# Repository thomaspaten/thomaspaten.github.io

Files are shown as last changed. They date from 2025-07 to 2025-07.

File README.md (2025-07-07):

# Arduino-Based Incubator Environmental Control System

## System Overview

This Arduino-based incubator environmental control system maintains precise temperature and humidity conditions across three distinct zones (TOP, BOT, and EXT) within a repurposed refrigerator housing, optimizing insulation and structural stability. Utilizing AHT20 sensors, PWM-controlled fans, dimmers and 100w incandescent lightbulbs. The system features advanced error handling, non-blocking operation, and biological process optimization.

### Wiring plan

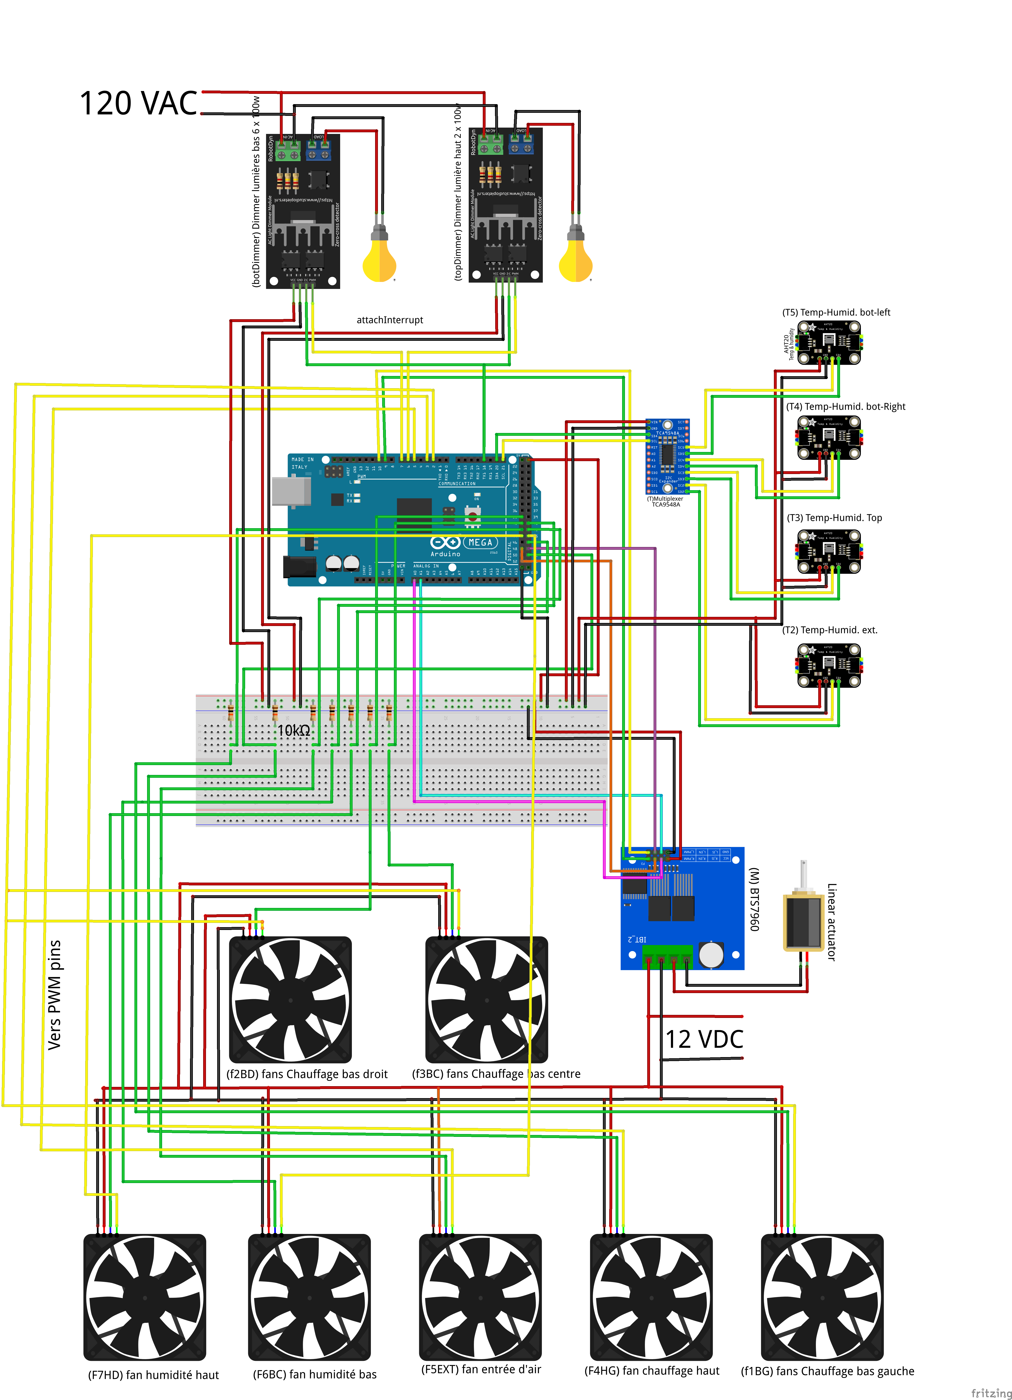
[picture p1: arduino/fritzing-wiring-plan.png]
Fritzing Wiring Plan


**Key Features:**

- Multi-zone climate control
- Redundant sensor systems
- Adaptive control algorithms
- Real-time monitoring
- Automatic failure recovery

---

# 1. System Architecture

## 1.1 Hardware Infrastructure

### 1.1.1 Microcontroller Configuration

The system is built on the **Arduino Mega 2560** platform, chosen for its extensive I/O capabilities and multiple hardware timers.

**Specifications:**

- **Processor**: ATmega2560 @ 16 MHz
- **Memory**: 256KB Flash, 8KB SRAM, 4KB EEPROM
- **Digital I/O**: 54 pins (15 PWM capable)
- **Analog Inputs**: 16 channels (10-bit resolution)
- **Hardware Timers**: 6 timers for precise PWM control

**Timer Allocation:**

```
Timer 0: Arduino millis() and delay() functions
Timer 1: Available for future expansion
Timer 2: Available for future expansion
Timer 3: PWM for pins 2, 3, 5 (fan control)
Timer 4: Available for future expansion
Timer 5: PWM for pins 44, 45 (fan control)
```

### 1.1.2 I2C Bus Architecture

The I2C communication backbone enables multiple identical sensors on a single bus through multiplexing.

**Physical Connection:**

```
Arduino Mega 2560
├── Pin 20 (SDA) ──┐
├── Pin 21 (SCL) ──┤
                   │
                   └─→ TCA9548A I2C Multiplexer (Address: 0x70)
                       ├── Channel 0: [Unused]
                       ├── Channel 1: [Unused]
                       ├── Channel 2: EXT Sensor (External/exterior)
                       ├── Channel 3: TOP Sensor (Upper Chamber)
                       ├── Channel 4: BOT_D Sensor (Bottom Door-side)
                       ├── Channel 5: BOT_G Sensor (Bottom Glass-side)
                       ├── Channel 6: [Reserved for expansion]
                       └── Channel 7: [Reserved for expansion]
```

**I2C Communication Parameters:**

- **Bus Speed**: 100 kHz (standard mode)
- **Pull-up Resistors**: 4.7kΩ on SDA and SCL
- **Multiplexer Control**: Single-byte channel selection
- **Error Detection**: ACK/NACK monitoring

### 1.1.3 Sensor Specifications (AHT20)

The AHT20 is a calibrated digital temperature and humidity sensor with I2C interface.

**Technical Specifications:**

| Parameter | Value |
| --- | --- |
| Temperature Range | -40°C to +85°C |
| Temperature Accuracy | ±0.3°C |
| Temperature Resolution | 0.01°C |
| Humidity Range | 0-100% RH |
| Humidity Accuracy | ±2% RH |
| Humidity Resolution | 0.024% RH |
| Response Time | 5-30 seconds |
| Supply Voltage | 2.0-5.5V |
| Supply Current | 23µA (typical) |
| Communication | I2C (max 400kHz) |

**Sensor Placement Rationale:**

- **EXT**: Monitors exterior conditions for compensation algorithms
- **TOP**: Upper chamber (hatcher), where warm air accumulates
- **BOT_D**: Bottom chamber (setter), where warm air accumulates on the right
- **BOT_G**: Bottom chamber (setter), where warm air accumulates on the left

## 1.2 Fan System Detailed Analysis

### 1.2.1 Fan Distribution and Purpose

The seven-fan system creates controlled airflow patterns for optimal environmental conditions.

**Fan Configuration Table:**

| Fan ID | Location | Pin | Function | Control Strategy |
| --- | --- | --- | --- | --- |
| F1BG | Bottom Chamber | 2 | Circulation | Temperature-based |
| F2BD | Bottom Chamber | 2 | Circulation | Temperature-based |
| F3BC | Bottom Chamber | 2 | Circulation | Temperature-based |
| F4HG | Top Chamber | 3 | Circulation | Temperature-based |
| F5EXT  | Exterior | 5 | Air exchange | Temp/Humidity hybrid |
| F6BC | Bottom Chamber | 45  | Humidity control | Humidity-based |
| F7HD | Top Chamber | 44  | Humidity control | Humidity-based |

**Shared PWM Design:** F1BG, F2BD, and F3BC share pin 2 to ensure synchronized operation

### 1.2.2 PWM Control Resolution

The system uses 8-bit PWM for fan speed control, providing 256 discrete speed levels.

**Speed Mapping:**

```cpp
// Percentage to PWM conversion
uint8_t percentageToPWM(uint8_t percentage) {
    return map(percentage, 0, 100, 0, 255);
}
```

**Predefined Speed Levels:**

| Level | Percentage | PWM Value | Use Case |
| --- | --- | --- | --- |
| OFF | 0% | 0 | No airflow needed |
| VERY_LOW | 25% | 64 | Minimal circulation |
| LOW | 50% | 128 | Gentle airflow |
| MEDIUM | 75% | 191 | Normal operation |
| HIGH | 100% | 255 | Maximum cooling/circulation |

**PWM Frequency:**

- Default: 490 Hz (Timer 3 and Timer 5)
- Audible noise: Minimal at this frequency

### 1.2.3 Tachometer Feedback System

Each fan provides RPM feedback through a tachometer output, enabling closed-loop monitoring.

**Tachometer Signal Characteristics:**

- **Type**: Open-collector output (requires pull-up resistor)
  - The pull-up resistor prevents a pin from being "floating," meaning it's neither high nor low, which can lead to unpredictable behavior.
- **Pulses per Revolution**: 2 (standard for 4-pole motors)
- **Signal Level**: 0-5V square wave

**Non-Blocking Pulse Measurement:**

```cpp
struct PulseData {
    unsigned long startTime = 0;  // Microsecond timestamp
    unsigned long duration = 0;   // Pulse width in microseconds
    bool pulseDetected = false;   // State tracking
};

// RPM Calculation
RPM = 60,000,000 / (pulse_duration × 4)
// Where: 60,000,000 = microseconds per minute
//        4 = 2 pulses/rev × 2 (for full period)
```

**Validation Ranges:**

- Minimum pulse: 1,000 µs (60,000 RPM - unrealistic, filtered)
- Maximum pulse: 1,000,000 µs (60 RPM - stall detection)

## 1.3 Heating System Architecture

### 1.3.1 Dimmer Control Implementation

The heating system uses AC phase control through TRIAC dimmers for precise temperature regulation.

**Hardware Components:**

- **Zero-Cross Detector**: Pin 18 (interrupt-capable)
- **TRIAC Driver (TOP)**: Pin 6
- **TRIAC Driver (BOT)**: Pin 7
- **Library**: `dimmable_light_linearized.h`

**Power Control Levels:**

| Setting | Power | Purpose |
| --- | ----- | --- |
| OFF | 0% | No heating required |
| LOW | 40% | Maintenance heating |
| MEDIUM  | 60% | [Unused in current config] |
| HIGH | 80% | Rapid temperature recovery |

**Safety Limitation:** Maximum 80% power prevents TRIAC overheating and extends the incandescent light bulb (100w) life.

### 1.3.2 AC Phase Control

The dimmer implements phase control for power regulation.

**Operating Principle:**

1. **Zero-Cross Detection**: Identifies AC waveform crossing zero volts
2. **Phase Delay**: Calculates delay based on desired power
3. **TRIAC Firing**: Triggers conduction at calculated point
4. **Power Delivery**: Earlier firing = more power

**Timing Calculations:**

```
AC Period = 16.67ms (60Hz) or 20ms (50Hz)
Half Period = 8.33ms (60Hz) or 10ms (50Hz)
Phase Angle = (1 - Power%) × Half Period
```

**Linear Compensation:** The library compensates for non-linear power delivery:

- Raw phase control: Power ∝ (Phase Angle)²
- Linearized output: Power ∝ Brightness setting

# 2. Environmental Control Algorithms

## 2.1 Temperature Control

### 2.1.1 TOP Chamber (Hatcher) Temperature Logic

The TOP chamber maintains optimal incubation temperature through coordinated heater and fan control.

**Temperature Zones and Responses:**

| Zone | Temperature Range | Heater Action | Fan F4HG Action | Rationale |
| --- | --- | --- | --- | --- |
| VERY_LOW | < 36.0°C | 80% Power | 100% Speed | Rapid warming with maximum circulation |
| LOW | 36.0-37.50°C | 40% Power | 75% Speed | Gentle warming approaching target |
| OPTIMAL  | 37.50-37.60°C | 0% Power | 50% Speed | Maintain with circulation only |
| HIGH | > 37.60°C | 0% Power | 100% Speed | Active cooling via air exchange with exterior |

**Control Logic Visualization:**

```
Temperature (°C)
    │
<36.0├─── VERY_LOW ─── Heater: 80%, Fan: 100%
    │
37.50├─── LOW ─────── Heater: 40%, Fan: 75%
    │
37.60├─── OPTIMAL ─── Heater: 0%, Fan: 50%
    │
  >  ├─── HIGH ────── Heater: 0%, Fan: 100%
    │
```

### 2.1.2 BOTTOM Chamber (Setter) Temperature Logic

The BOTTOM chamber uses averaged readings from two sensors to compensate for sensor inaccuracies.

**Dual Sensor Averaging:**

```cpp
float botTemperatureAvg = (botSensorData.temperatureD + botSensorData.temperatureG) / 2;
```

Averaging prevents control bias from single-point measurement

**Temperature Zones and Responses:**

| Zone | Temperature Range | Heater Action | Fans F1-F3 Action | Notes |
| --- | --- | --- | --- | --- |
| VERY_LOW | < 36.0°C | 80% Power | 100% Speed | Emergency heating |
| LOW | 36.0-37.54°C | 40% Power | 75% Speed | Normal warming |
| OPTIMAL  | 37.54-37.68°C | 0% Power | 50% Speed | Target achieved |
| HIGH | > 37.68°C | 0% Power | 100% Speed | Cooling required  |

### 2.1.3 External Temperature Compensation Algorithm

The system adapts to exterior conditions by modifying bottom chamber heater setpoints.

**Compensation Logic:**

```cpp
if (extTemperature < 18.0°C) {  // VERY_LOW_TEMP_EXT
    // Increase all bottom dimmer settings by 10%
    adjustedDimmerLow = DIMMER_LOW + 10;    // 40% → 50%
    adjustedDimmerHigh = DIMMER_HIGH + 10;  // 80% → 90%
} else if (extTemperature > 22.0°C) {  // LOW_TEMP_EXT
    // Decrease all bottom dimmer settings by 10%
    adjustedDimmerLow = max(0, DIMMER_LOW - 10);   // 40% → 30%
    adjustedDimmerHigh = max(0, DIMMER_HIGH - 10); // 80% → 70%
}
```

**Rationale:**

- **Cold exterior (<18°C)**: Increased heating to compensate for cool air coming from the exterior
- **Warm exterior (>22°C)**: Reduced heating to compensate for warm air coming from the exterior
- **Neutral Zone (18-22°C)**: Standard control parameters

## 2.2 Humidity Control

### 2.2.1 TOP Chamber Humidity Management

The TOP chamber requires higher humidity for hatching.

**Humidity Control Matrix:**

| State | RH Range | Fan F7HD | Strategy |
| --- | --- | --- | --- |
| VERY_LOW | < 55% | 100% | Maximum humidification |
| LOW | 55-62% | 100% | Active humidification |
| MEDIUM | 62-68% | 50% | Maintenance mode |
| HIGH | > 68% | 0% | Natural dehumidification |

**Humidity Source:**

- Water pan and fan
- Variations of fan speeds manage evaporation rate by blowing air on the water pan.

### 2.2.2 BOTTOM Chamber Humidity Management

The BOTTOM chamber maintains lower humidity for setting.

**Humidity Control Matrix:**

| State | RH Range | Fan F6BC | Purpose |
| --- | --- | --- | --- |
| VERY_LOW | < 40% | 100% | Prevent desiccation |
| LOW | 40-45% | 75% | Increase moisture |
| MEDIUM | 45-48% | 50% | Maintain balance |
| HIGH | > 52% | 0% | Allow natural reduction |

### 2.2.3 Humidity Override Mechanism

Critical humidity levels trigger emergency ventilation regardless of temperature.

**Override Implementation:**

```cpp
// In adjustFanAndDimmerForExt()
if (botHumidityAvg > 55.0%) {  // HIGH_HUMIDITY_BOT threshold
    analogWrite(PWM_F5EXT, percentageToPWM(FAN_HIGH));  // Force 100%
    // Message: "Fan F5EXT: High Speed (EXT_SENSOR override - Bot Humidity > 55.0%)"
}
```

**Override Cascade:**

1. Bottom humidity exceeds 55%
2. F5EXT forced to 100% (overrides temperature control)
3. Fresh, dry air exchanges with humid internal air
4. Continues until humidity drops below threshold

## 2.3 External Air Exchange Logic

### 2.3.1 Normal Operation

The external fan (F5EXT) operates on a hierarchical decision tree.

**Decision Priority (Highest to Lowest):**

```
1. IF (BOT_HUMIDITY > 55%):
      F5EXT = 100%  [Humidity Override]
      
2. ELSE IF (EXT_TEMP > 36.8°C):
      F5EXT = 100%  [Active Cooling]
      
3. ELSE:
      F5EXT = 25%   [Baseline Ventilation]
```

**Operational Modes:**

| Mode | Condition | Fan Speed | Purpose |
| --- | --- | --- | --- |
| Emergency Dehumidification | Bot RH > 55% | 100% | Moisture removal |
| Active Cooling | Ext Temp > 36.8°C | 100% | Cooling of electronic enclosure |
| Baseline Ventilation | All other conditions | 25% | Gas exchange |

### 2.3.2 Air Quality Management

Continuous baseline ventilation ensures biological viability.

**Gas Exchange Requirements:**

- **O₂ Supply**: Embryonic respiration consumes oxygen
- **CO₂ Removal**: Metabolic waste product must be expelled
- **VOC Dilution**: Volatile organic compounds from biological processes

# 3. Sensor Reading and Data Processing

## 3.1 Timing Architecture

### 3.1.1 Reading Cycle Timeline

The sensor reading process follows a deterministic schedule to ensure predictable system behavior.

**Complete Cycle Breakdown:**

```
Time (ms)    Event                           Duration    Cumulative
─────────────────────────────────────────────────────────────────
0            Cycle Start                     -           0ms
0-500        Read EXT sensor (Channel 2)     500ms       500ms
500-1000     Read TOP sensor (Channel 3)     500ms       1000ms
1000-1500    Read BOT_D sensor (Channel 4)   500ms       1500ms
1500-2000    Read BOT_G sensor (Channel 5)   500ms       2000ms
2000-2100    Calculate averages              100ms       2100ms
2100-2200    Adjust controls                 100ms       2200ms
2200-2300    Update displays                 100ms       2300ms
2300-3000    Idle time                       700ms       3000ms
3000         Next cycle begins               -           -
```

**Timing Guarantees:**

- Maximum sensor read time: 500ms (includes retries)
- Control update latency: <100ms after sensor read
- Worst-case cycle time: 3000ms
- Watchdog margin: 5000ms (8000ms timeout - 3000ms cycle)

### 3.1.2 Non-Blocking Implementation

The system uses state machines to prevent blocking operations.

**Main Loop State Machine:**

```cpp
// Sensor reading states
static bool readingInProgress = false;
static int sensorIndex = 0;

// Cycle trigger
if (currentMillis - previousSensorMillis >= readInterval && !readingInProgress) {
    previousSensorMillis = currentMillis;
    sensorIndex = 0;
    readingInProgress = true;
}

// Sensor reading progression
if (readingInProgress && currentMillis - sensorDelayMillis >= sensorDelayInterval) {
    // Read current sensor
    // Increment sensorIndex
    // Set readingInProgress = false when complete
}
```

**Benefits:**

- No delay() calls that would block execution
- Continuous fan RPM monitoring
- Responsive to emergency conditions
- Prevents watchdog timeouts

## 3.2 Data Validation and Filtering

### 3.2.1 Validation Criteria

All sensor readings undergo validation before use.

**Validation Function:**

```cpp
bool isValidReading(float value, float minVal, float maxVal) {
    return !isnan(value) && value >= minVal && value <= maxVal;
}
```

**Range Limits:**

| Parameter | Minimum | Maximum | Action if Invalid  |
| --- | --- | --- | --- |
| Temperature | -40.0°C | +85.0°C | Use fallback value |
| Humidity | 0.0% | 100.0%  | Use fallback value |

**NaN Detection:**

- Caused by: Communication errors, sensor failure
- Response: Immediate fallback to calculated estimate

### 3.2.2 Moving Average Implementation

The system maintains 100-sample circular buffers to get an average of the last 100 sensors readings.

**Buffer Structure:**

```cpp
// Temperature arrays
float topTemperatures[100];
float botDTemperatures[100];
float botGTemperatures[100];

// Humidity arrays
float topHumidities[100];
float botDHumidities[100];
float botGHumidities[100];

// Circular index
int readingIndex = 0;
```

**Average Calculation:**

```cpp
float calculateAverage(float readings[], int n) {
    float sum = 0;
    for (int i = 0; i < n; i++) {
        sum += readings[i];
    }
    return sum / n;
}
```

**Filtering Performance:**

- **Sample Window**: 300 seconds (100 samples × 3 seconds)
- **Effective Resolution**: 0.03°C (from 0.3°C sensor accuracy)

## 3.3 Failure Management

### 3.3.1 Sensor Health Tracking

Each sensor maintains health statistics for reliability monitoring.

**Health Metrics:**

```cpp
struct SensorHealth {
    int successfulReads = 0;  // Cumulative success count
    int failedReads = 0;      // Cumulative failure count
};
```

**Failure Escalation:**

1. **Single Failure**: Retry up to 3 times
2. **Persistent Failure**: Increment failure counter
3. **Chronic Failure**: After 10 failures, disable sensor
4. **Recovery Check**: Every 60 seconds, attempt re-enable

**Health Status Display every 300 seconds (Serial Monitor):**

```
Sensor Health Status:
EXT - Successful Reads: 1200, Failed Reads: 2
TOP - Successful Reads: 1198, Failed Reads: 4
BOT_D - Successful Reads: 1201, Failed Reads: 1
BOT_G - Successful Reads: 1202, Failed Reads: 0
```

### 3.3.2 Fallback Strategy

Intelligent fallback values maintain system operation during sensor failures.

**Temperature Fallback Logic:**

```cpp
float getFallbackTemperature(int sensorIndex) {
    switch (sensorIndex) {
        case EXT:   return 25.0;  // Assume room temperature
        case TOP:   return botSensorData.temperatureD - 0.3;  // Thermal model
        case BOT_D: return botSensorData.temperatureG;  // Adjacent sensor
        case BOT_G: return botSensorData.temperatureD;  // Adjacent sensor
    }
}
```

**Humidity Fallback Logic:**

```cpp
float getFallbackHumidity(int sensorIndex) {
    switch (sensorIndex) {
        case EXT:   return 50.0;  // Assume moderate humidity
        case TOP:   return botSensorData.humidityD + 15.0;  // Evaporation model
        case BOT_D: return botSensorData.humidityG;  // Adjacent sensor
        case BOT_G: return botSensorData.humidityD;  // Adjacent sensor
    }
}
```

**Fallback Rationale:**

- **Thermal Stratification**: TOP is typically 0.3°C cooler than BOT
- **Humidity Gradient**: TOP is ~15% more humid due to hatching requirements
- **Adjacent Correlation**: BOT sensors typically within 0.1°C of each other

## 3.4 I2C Communication Robustness

### 3.4.1 Channel Selection State Machine

Multi-stage error handling ensures reliable multiplexer control.

**State Definitions:**

```
State 0: Idle - Ready to start new transmission
State 2: Retry - Previous attempt failed, waiting to retry
State 3: Bus Reset - Multiple failures, attempting recovery
```

**State Transitions:**

```
    ┌─────┐ Success  ┌─────┐
    │  0  ├─────────→│Done │
    │Idle │          └─────┘
    └──┬──┘
       │ Failure
       ▼
    ┌─────┐ Retry<3   ┌─────┐
    │  2  ├──────────→│ 0   │
    │Retry│           │Idle │
    └──┬──┘           └─────┘
       │ Retry≥3
       ▼
    ┌─────┐ Reset OK  ┌─────┐
    │  3  ├──────────→│ 0   │
    │Reset│           │Idle │
    └─────┘           └─────┘
```

**Timing Parameters:**

- Retry delay: 50ms
- Maximum retries: 3
- Bus reset duration: 100ms
- Total timeout: 250ms

### 3.4.2 Bus Recovery Mechanism

Hardware-level recovery clears stuck I2C devices.

**Recovery Sequence:**

```cpp
void resetI2CBus() {
    // 1. Take control of I2C pins
    pinMode(SDA_PIN, OUTPUT);
    pinMode(SCL_PIN, OUTPUT);
    
    // 2. Clock out stuck devices (9 pulses)
    for (int i = 0; i < 9; i++) {
        digitalWrite(SCL_PIN, HIGH);
        delayMicroseconds(5);
        digitalWrite(SCL_PIN, LOW);
        delayMicroseconds(5);
    }
    
    // 3. Generate STOP condition
    digitalWrite(SDA_PIN, LOW);   // SDA low
    delayMicroseconds(5);
    digitalWrite(SCL_PIN, HIGH);  // SCL high
    delayMicroseconds(5);
    digitalWrite(SDA_PIN, HIGH);  // SDA high (STOP)
    
    // 4. Return control to I2C hardware
    pinMode(SDA_PIN, INPUT);
    pinMode(SCL_PIN, INPUT);
    Wire.begin();
}
```

**Recovery Triggers:**

- 3 consecutive NAKs from multiplexer
- Wire.endTransmission() returns error
- Sensor initialization timeout

# 4. Control System Dynamics

Different subsystems operate at optimized update rates.

**Update Frequency Table:**

| Subsystem | Frequency  | Period | Priority |
| --- | --- | --- | --- |
| Sensor Reading | 0.33 Hz | 3 seconds  | High |
| Control Output | 0.33 Hz | 3 seconds  | High |
| Fan RPM | Continuous | ~1ms | Low |
| Actuator State | Continuous | <1ms | Medium |
| Health Check | 0.017 Hz | 60 seconds | Low |
| Debug Print | 0.011 Hz | 90 seconds | Lowest |

**Timing Hierarchy:**

1. **Critical Path**: Sensor → Control → Output (3.2 seconds)
2. **Background Tasks**: RPM monitoring (continuous)
3. **Maintenance**: Health checks (60 seconds)
4. **Diagnostics**: Debug output (90 seconds)

# 5. Advanced Features

## 5.1 Linear Actuator System

### 5.1.1 Movement Sequence

The actuator system provides programmable eggs rotation.

**Complete Sequence Timeline:**

| Phase | Duration | Action | Purpose |
| --- | --- | --- | --- |
| Initial Retract | 60 seconds | Full retraction | Return to home position |
| Initial Stop | 10 seconds | Hold position | Stabilization |
| Extension Cycle (×11)  | | | |
| - Extend | 3 seconds  | Forward movement  | Agitation |
| - Stop | 13 minutes | Hold position | Settling time |
| Retraction Cycle (×11) | | | |
| - Retract | 3 seconds  | Backward movement | Return stroke |
| - Stop | 13 minutes | Hold position | Settling time |
| System Reset | Immediate  | Watchdog timeout  | Clean restart |

**Total Cycle Duration:**

```
Initial: 60 + 10 = 70 seconds
Extensions: 11 × (3 + 780) = 8,613 seconds
Retractions: 11 × (3 + 780) = 8,613 seconds
Total: 17,296 seconds ≈ 4.8 hours
```

**Motor Control Logic:**

```cpp
void controlMotor(bool enable, int dir) {
    if (enable) {
        digitalWrite(R_PWM, dir == 1 ? HIGH : LOW);   // Forward
        digitalWrite(L_PWM, dir == -1 ? HIGH : LOW);  // Reverse
        digitalWrite(R_EN, HIGH);  // Enable right
        digitalWrite(L_EN, HIGH);  // Enable left
    } else {
        digitalWrite(R_EN, LOW);   // Disable all
        digitalWrite(L_EN, LOW);
        digitalWrite(R_PWM, LOW);
        digitalWrite(L_PWM, LOW);
    }
}
```

### 5.1.2 Purpose Analysis

The actuator system simulates natural incubation movements.

**Biological Rationale:**

1. **Prevents Adhesion**
    - Embryo can stick to membrane
    - Periodic movement prevents attachment
    - Critical during days 3-18 of incubation
    
2. **Uniform Development**
    - Redistributes nutrients in albumen
    - Prevents yolk stratification
    - Ensures even temperature distribution
    
3. **Gas Exchange**
    - Movement enhances air cell formation
    - Facilitates CO₂ removal from egg
    - Improves O₂ penetration
    
4. **Natural Simulation**
    - Mimics parent bird movements
    - 3-second duration = gentle repositioning

**Movement Profile:**

```
Position
    │     ┌─3s─┐     ┌─3s─┐
MAX ├─────┘    └──-──┘    └────-                              
    │ 13min     13min      13min
```

## 5.2 Watchdog Timer Implementation

### 5.2.1 Normal Operation

The watchdog prevents system lockup through automatic reset.

**Configuration:**

```cpp
// In setup()
wdt_enable(WDTO_8S);  // 8-second timeout

// Throughout loop()
wdt_reset();  // Called multiple times per cycle
```

**Reset Prevention Points:**

1. Start of main loop
2. After sensor reading
3. During long operations

**Timeout Scenarios:**

- I2C bus permanently locked
- Infinite loop in user code
- Hardware malfunction
- Stack overflow

### 5.2.2 Intentional Reset

The system uses watchdog for controlled restart after actuator sequence.

**Reset Implementation:**

```cpp
if (sequenceCount >= REPETITIONS) {
    // After last retraction
    wdt_enable(WDTO_15MS);  // 15ms timeout
    while (true) {
        // Intentional infinite loop
        // Watchdog will reset in 15ms
    }
}
```

**Reset Benefits:**

- Clears accumulated errors
- Resets memory allocation
- Re-initializes all peripherals
- Returns actuator to home
- Provides known starting state

**Reset Sequence:**

1. Watchdog expires (15ms)
2. Processor resets
3. Bootloader runs (2 seconds)
4. Setup() executes
5. Normal operation resumes

## 5.3 Debug and Monitoring

### 5.3.1 Cyclic Reporting

Debug output occurs every 30 sensor cycles (90 seconds).

**Serial Monitor Contents:**

```
=========================================
EXT - Temperature: 22.3 °C, Humidity: 45.2 %
TOP - Temperature: 37.52 °C, Humidity: 66.8 %
BOT-Av - Temperature: 37.58 °C, Humidity: 47.3 %

EXT: F5EXT: 1250 RPM
TOP: F4HG: 2100 RPM, F7HD: 0 RPM
BOT: F1BG: 1800 RPM, F2BD: 1850 RPM, F3BC: 1820 RPM, F6BC: 950 RPM

TOP Average 100 Temperature:   37.51 °C
BOT_D Average 100 Temperature: 37.56 °C
BOT_G Average 100 Temperature: 37.59 °C

TOP Average 100 Humidity:   66.5 %
BOT_D Average 100 Humidity: 46.8 %
BOT_G Average 100 Humidity: 47.8 %

Next Linear actuator sequence: 5 of 11 EXTENDING_SEQUENCE
=========================================

Sensor Health Status:
EXT - Successful Reads: 1200, Failed Reads: 2
TOP - Successful Reads: 1198, Failed Reads: 4
BOT_D - Successful Reads: 1201, Failed Reads: 1
BOT_G - Successful Reads: 1202, Failed Reads: 0
=========================================
```

### 5.3.2 Conditional Logging

Intelligent logging reduces serial bandwidth usage.

**shouldPrint() Logic:**

```cpp
bool shouldPrint() {
    return cycleCounter % PRINT_CYCLE_INTERVAL == 0;
}
// PRINT_CYCLE_INTERVAL = 30 cycles = 90 seconds
```

**Benefits:**

- Reduces processing overhead
- Prevents serial buffer overflow
- Maintains 115200 baud efficiency
- Allows real-time monitoring without flooding

# 6. System Integration and Real-World Behavior

## 6.1 Startup Sequence

The system follows a deterministic initialization sequence.

**Startup Timeline:**

| Time | Phase | Actions | Duration |
| --- | --- | --- | --- |
| 0ms | Power On | Bootloader execution | 2000ms |
| 2000ms  | Setup Start | Serial initialization | 10ms |
| 2010ms  | GPIO Config | Pin modes, initial states | 50ms |
| 2060ms  | Peripheral Init  | Dimmers, I2C, Watchdog | 100ms |
| 2160ms  | Sensor Discovery | Channel scan, AHT20 init  | 5000ms max |
| 7160ms  | Control Start | First sensor read | 3000ms |
| 10160ms | Steady State | Normal operation | Continuous |

**Initialization Details:**

1. **GPIO Configuration**
    
    ```cpp
    // Outputs set to safe states
    All PWM pins → 0 (fans off)
    Heater pins → 0 (heaters off)
    Motor pins → 0 (actuator stopped)
    ```
    
2. **Sensor Discovery Process**
    
    ```cpp
    For each channel (2-5):
      - Select multiplexer channel
      - Attempt AHT20.begin()
      - 5-second timeout per sensor
      - Continue with available sensors
    ```
    
3. **Initial Control State**
    
    - All fans: 0% (will ramp up based on readings)
    - All heaters: 0% (safety first)
    - Actuator: Begin 60-second retraction to ensure actuator is completely retracted before starting sequence.

## 6.2 Steady-State Operation

### 6.2.1 24-Hour Profile Example

The system adapts to environmental changes.

| Time Period | External Conditions | System Response |
| --- | --- | --- |
| 00:00-06:00 | Cool (15-18°C), Stable | Increased heating, minimal ventilation |
| 06:00-09:00 | Warming (18-22°C) | Reduced heating, baseline ventilation  |
| 09:00-15:00 | Warm (22-30°C) | Minimal heating, increased ventilation |
| 15:00-18:00 | Peak (28-35°C) | No heating, maximum cooling efforts |
| 18:00-21:00 | Cooling (25-20°C) | Gradual heating increase |
| 21:00-00:00 | Cool (20-15°C) | Return to night settings |

## 6.3 Failure Scenarios and Recovery

### 6.3.1 Sensor Failure Cascade

**Failure Progression:**

```
1. Single Sensor Failure
   ├── Use fallback value
   ├── Continue normal operation
   └── Log failure for diagnostics

2. Paired Sensor Failure (BOT_D + BOT_G)
   ├── Use TOP - 0.3°C for temperature
   ├── Use TOP - 15% for humidity
   └── Increase safety margins

3. Zone Failure (All BOT or TOP)
   ├── Use remaining zone data
   ├── Apply conservative estimates
   └── Alert via serial output

4. Total Sensor Failure
   ├── Use default values (25°C, 50% RH)
   ├── Run fans at 50%
   ├── Run heaters at 20%
   └── Safe mode operation
```

**Recovery Mechanisms:**

- Automatic retry every 60 seconds
- I2C bus reset on communication failure
- Sensor re-initialization attempts
- Gradual trust rebuilding after recovery

# 7. Biological Considerations

## 7.1 Incubation Requirements

### 7.1.1 Temperature Precision

Critical temperature ranges for successful incubation.

**Species-Specific Requirements:**

| Species | Optimal Range | Critical Limits | Duration |
| --- | --- | --- | --- |
| Chicken | 37.5-37.8°C | 36.1-39.4°C | 21 days  |
| Duck | 37.5°C | 36.0-39.0°C | 28 days  |
| Quail | 37.6-37.8°C | 36.5-39.0°C | 17 days  |
| Turkey  | 37.5-37.6°C | 36.0-39.0°C | 28 days  |

**Temperature Impact on Development:**

- **Too Low (<36°C)**: Delayed development, weakness
- **Optimal (37.5°C)**: Normal development rate
- **Too High (>39°C)**: Accelerated but abnormal development
- **Lethal (>40°C)**: Protein denaturation, death

### 7.1.2 Humidity Management

Moisture control for proper development.

**Humidity Requirements by Stage:**

| Incubation Stage | Days  | Target RH | Purpose |
| --- | ----- | --- | --- |
| Early | 1-7 | 50-60% | Prevent excess water loss |
| Middle | 8-18  | 45-55% | Controlled dehydration |
| Late | 19-21 | 65-75% | Facilitate hatching |

**Humidity Effects:**

- **Too Low (<40%)**: Excessive water loss, stuck chicks
- **Optimal (50-55%)**: Proper air cell development
- **Too High (>75%)**: Insufficient water loss, drowning

**Water Loss Targets:**

- Total loss: 12-15% of initial egg weight
- Daily rate: 0.5-0.7% of egg weight
- Monitored by candling

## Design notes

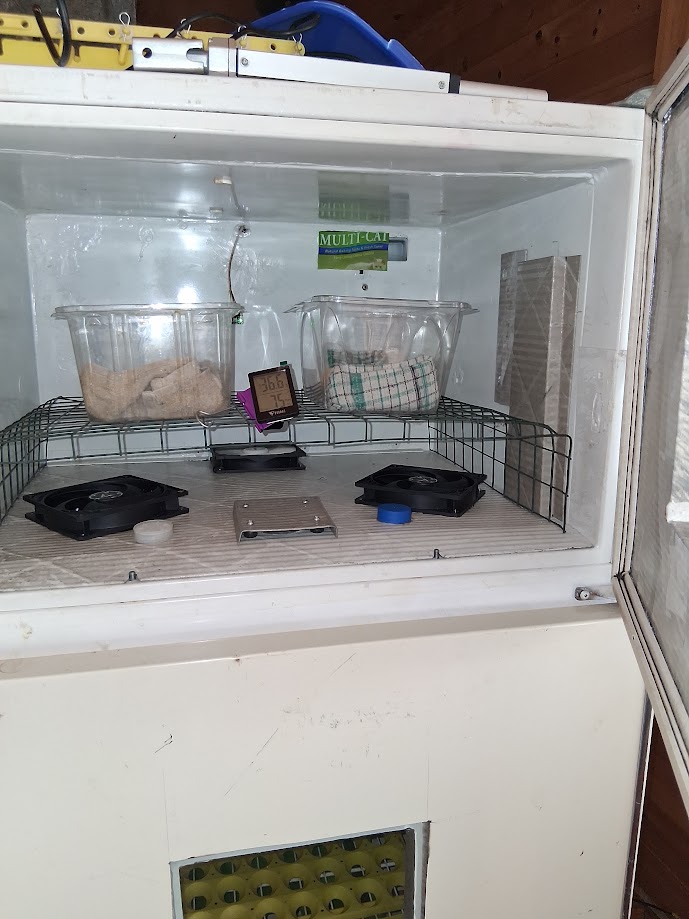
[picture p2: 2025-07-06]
dist/assets/top-section-D4AaJDt0.jpg

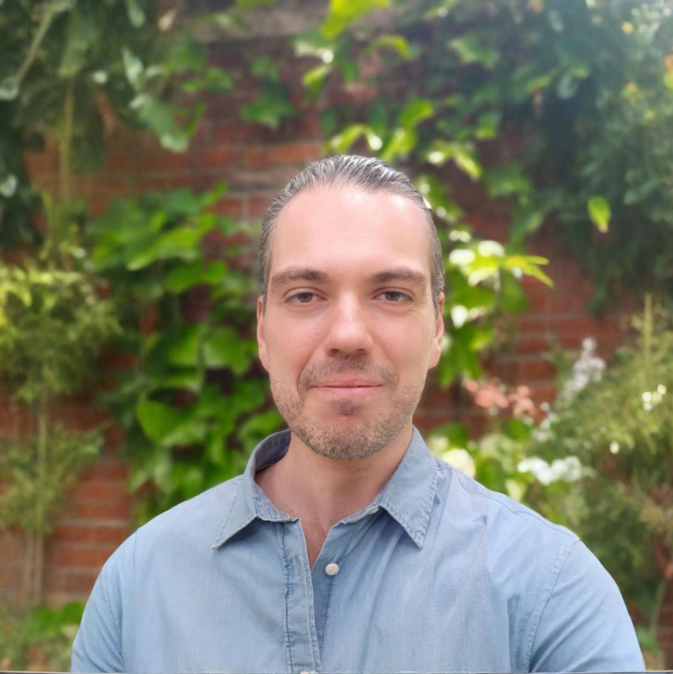
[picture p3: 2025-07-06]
dist/assets/linkedin-profile-MUepS1IG.png

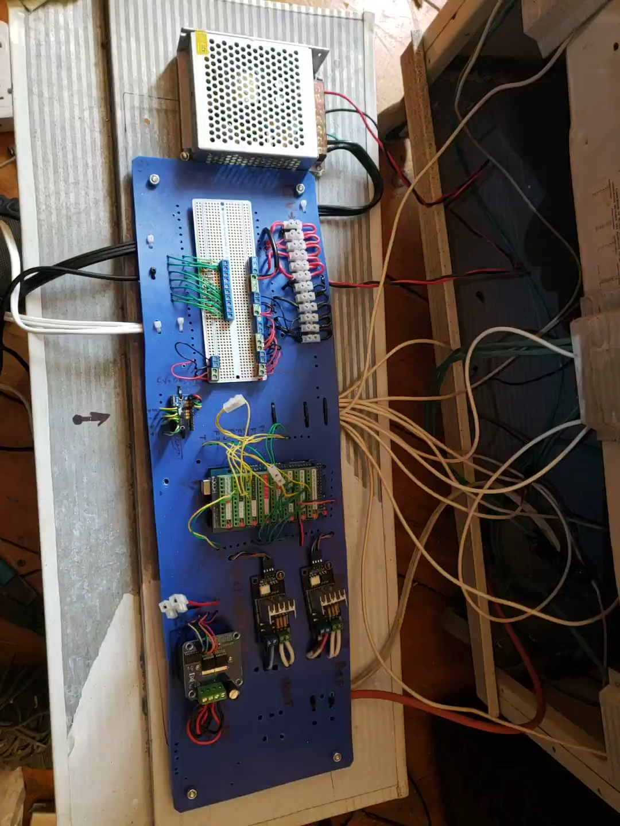
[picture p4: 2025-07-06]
dist/assets/arduino-circuit-CAp-xd5A.png

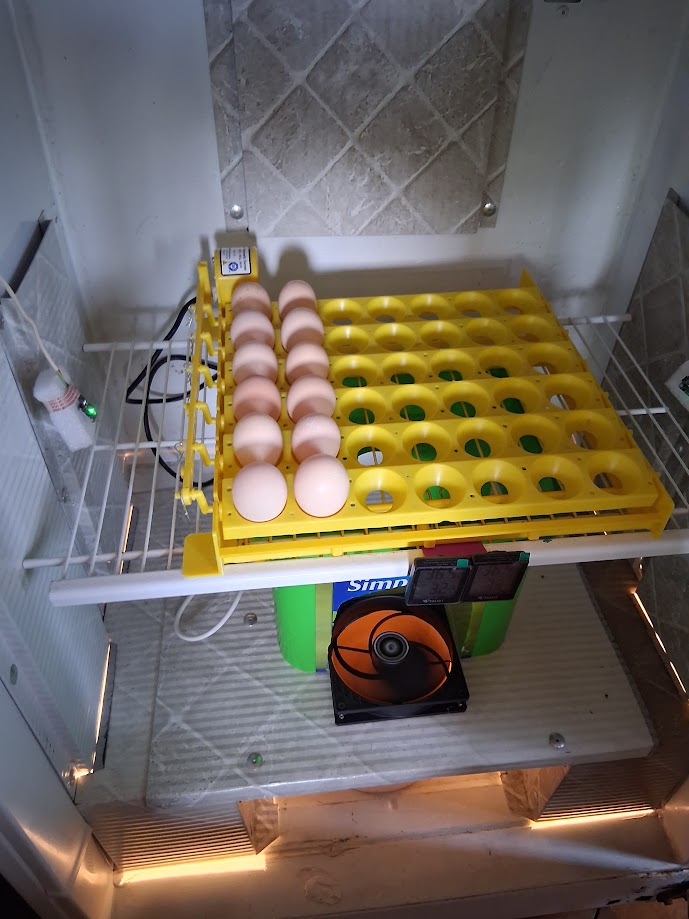
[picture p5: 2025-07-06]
dist/img/bottom-section.jpg

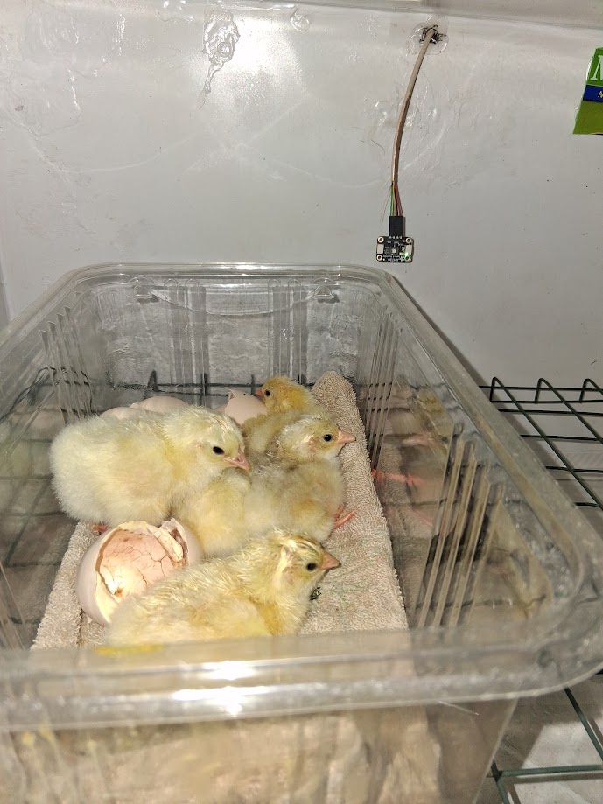
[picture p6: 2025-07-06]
dist/assets/hatched-chick-DnAsckwr.jpg

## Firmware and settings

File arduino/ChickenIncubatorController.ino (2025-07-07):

/*
VERY IMPORTANT
For <dimmable_light_linearized.h> to work, Arduino AVR board must be version 1.8.2 or lower 
(Menu - Tool - Board - Boards manager)
*/

/*
Summary of Conditions for Dimmers and Fans Adjustments

                  TEMPERATURE         DIMMER        FANS                          TARGET
Top
Very Low Temp     (< 36.0°C)	        High (80%)	  F4HG: High (100%)             -
Low Temp          (36.0°C - 37.35°C)	Low (40%)	    F4HG: Medium (75%)            -
Medium Temp       (37.35°C - 37.45°C)	Off (0%)	    F4HG: Low (50%)               37.2–37.5°C
High Temp         (> 37.45°C)	        Off (0%)	    F4HG: High (100%)             -

Very Low Humidity (< 55.0%)	          -	            F7HD: High (100%)             - 
Low Humidity      (55.0% - 65.0%)	    -	            F7HD: Medium (75%)            -
Medium Humidity   (65.0% - 74.0%)	    -	            F7HD: Very Low (25%)          65–75%
High Humidity     (> 74.0%)	          -	            F7HD: Off (0%)

Bot
Very Low Temp     (< 36.0°C)	        High (80%)	  F1BG_F2BD_F3BC: High (100%)   -
Low Temp          (36.0°C - 37.45°C)	Low (40%)	F1BG_F2BD_F3BC: Medium (75%)  -
Medium Temp       (37.45°C - 37.55°C)	Off (0%)	    F1BG_F2BD_F3BC: Low (50%)     37.5°C
High Temp         (> 37.55°C)	        Off (0%)	    F1BG_F2BD_F3BC: High (100%)   -

Very Low Humidity (< 40.0%)	          -	            F6BC: High (100%)             -
Low Humidity      (40.0% - 50.0%)	    -	            F6BC: Medium (75%)            -
Medium Humidity   (50.0% - 55.0%)	    -	            F6BC: Very Low (25%)          50–55%
High Humidity     (> 55.0%)	          -	            F6BC: Off (0%)                -

Ext
High Temp         (> 36.8°C)	        -	            F5EXT: High (100%)            -
Otherwise	                            -	            F5EXT: Very Low (25%)         -
*/

#include <Wire.h>                       // Library for I2C communication (sensors and multiplexer)
#include <Adafruit_AHTX0.h>             // Library for AHT20 temperature/humidity sensor
#include <dimmable_light_linearized.h>  // Library for controlling dimmable lights
#include <avr/wdt.h>                    // Library for watchdog timer (system reset on failure)

// ====================
// Constants
// ====================

// Printing cycles
constexpr int PRINT_CYCLE_INTERVAL = 30;  // Interval (in cycles) for printing debug info
constexpr int N_READINGS = 100;            // Number of readings for sensor temperature averaging

// ====================
// Pin Definitions
// ====================

// PWM Fan Pins (Default Arduino Mega frequency)
constexpr int PWM_F1BG_F2BD_F3BC = 2;  // Shared PWM pin for fans F1BG, F2BD, F3BC (Timer 3)
constexpr int PWM_F4HG = 3;            // PWM pin for fan F4HG (Timer 3)
constexpr int PWM_F5EXT = 5;           // PWM pin for fan F5EXT (Timer 3)
constexpr int PWM_F6BC = 45;           // PWM pin for fan F6BC (Timer 5)
constexpr int PWM_F7HD = 44;           // PWM pin for fan F7HD (Timer 5)

// TACH Fan Pins (for reading fan speed)
constexpr int TACH_F1BG = 42;   // TACH pin for fan F1BG (reads RPM)
constexpr int TACH_F2BD = 38;   // TACH pin for fan F2BD (reads RPM)
constexpr int TACH_F3BC = 40;   // TACH pin for fan F3BC (reads RPM)
constexpr int TACH_F4HG = 51;   // TACH pin for fan F4HG (reads RPM)
constexpr int TACH_F5EXT = 43;  // TACH pin for fan F5EXT (reads RPM)
constexpr int TACH_F6BC = 41;   // TACH pin for fan F6BC (reads RPM)
constexpr int TACH_F7HD = 47;   // TACH pin for fan F7HD (reads RPM)

// I2C Multiplexer Address
constexpr int TCA9548A_ADDRESS = 0x70;  // Address of TCA9548A I2C multiplexer

// Dimmable Light Pins
constexpr int dimmerZeroCrossPin = 18;  // Pin for zero-crossing detection (dimmer control)
constexpr int topDimmerOutputPin = 6;   // Pin for top dimmer output (brightness control)
constexpr int botDimmerOutputPin = 7;   // Pin for bottom dimmer output (brightness control)

// Motor driver pins (Linear Actuator)
constexpr int R_EN = 48;   // Right enable pin for motor driver
constexpr int L_EN = 49;   // Left enable pin for motor driver
constexpr int R_PWM = 10;  // Right PWM pin for motor driver
constexpr int L_PWM = 9;   // Left PWM pin for motor driver

// I2C Bus Reset Pins (assuming SDA = 20, SCL = 21 on Arduino Mega)
constexpr int SDA_PIN = 20;  // I2C SDA pin
constexpr int SCL_PIN = 21;  // I2C SCL pin

// ====================
// Constants
// ====================

// Number of Sensors
constexpr int NUM_SENSORS = 4;  // Total number of temp/humidity sensors

// Sensor Names (used to identify sensors in code and output)
enum SensorName { EXT, TOP, BOT_D, BOT_G };  // Enum for sensor naming

// Convert SensorName enum to readable string
const char* getSensorName(SensorName sensor) {
  switch (sensor) {
    case EXT: return "EXT";
    case TOP: return "TOP";
    case BOT_D: return "BOT_D";
    case BOT_G: return "BOT_G";
    default: return "UNKNOWN";
  }
}

// Temperature Thresholds
constexpr float VERY_LOW_TEMP_TOP = 36;    // Very low temp threshold for TOP sensor (°C)
constexpr float LOW_TEMP_TOP = 37.50;      // Low temp threshold for TOP sensor (°C) was 37.38
constexpr float HIGH_TEMP_TOP = 37.60;     // High temp threshold for TOP sensor (°C) was 37.48

constexpr float VERY_LOW_TEMP_BOT = 36;    // Very low temp threshold for BOT sensors (°C)
constexpr float LOW_TEMP_BOT = 37.54;      // Low temp threshold for BOT sensors (°C)
constexpr float HIGH_TEMP_BOT = 37.68;     // High temp threshold for BOT sensors (°C)

constexpr float VERY_LOW_TEMP_EXT = 18.0;  // Very low temp threshold for EXT sensor (°C)
constexpr float LOW_TEMP_EXT = 22.0;       // Low temp threshold for EXT sensor (°C)
constexpr float HIGH_TEMP_EXT = 36.8;      // High temp threshold for EXT sensor (°C)

// Humidity Thresholds
constexpr float VERY_LOW_HUMIDITY_TOP = 55.0;  // Very low humidity threshold for TOP (%)
constexpr float LOW_HUMIDITY_TOP = 62.0;       // Low humidity threshold for TOP (%) was 65
constexpr float MEDIUM_HUMIDITY_TOP = 68.0;    // Medium humidity threshold for TOP (%) was 74
constexpr float HIGH_HUMIDITY_TOP = 68.0;      // High humidity threshold for TOP (%) was 74

constexpr float VERY_LOW_HUMIDITY_BOT = 40.0;  // Very low humidity threshold for BOT (%)
constexpr float LOW_HUMIDITY_BOT = 45.0;       // Low humidity threshold for BOT (%) était 50
constexpr float MEDIUM_HUMIDITY_BOT = 48.0;    // Medium humidity threshold for BOT (%) était 55
constexpr float HIGH_HUMIDITY_BOT = 52.0;      // High humidity threshold for BOT (%) était 55

// Fan Speed Thresholds (in percentage)
constexpr int FAN_OFF = 0;        // Fan off (0% speed)
constexpr int FAN_VERY_LOW = 25;  // Fan speed at 25%
constexpr int FAN_LOW = 50;       // Fan speed at 50%
constexpr int FAN_MEDIUM = 75;    // Fan speed at 75%
constexpr int FAN_HIGH = 100;     // Fan speed at 100%

// Dimmer Brightness Thresholds (in percentage)
constexpr int DIMMER_OFF = 0;      // Dimmer off (0% brightness)
constexpr int DIMMER_LOW = 40;     // Dimmer brightness at 40%
constexpr int DIMMER_MEDIUM = 60;  // Dimmer brightness at 60%
constexpr int DIMMER_HIGH = 80;    // Dimmer brightness at 80%

// PWM and Timing Constants
constexpr int PWM_MAX_VALUE = 255;  // Max value for 8-bit PWM (100%)

// Sensor Timing
constexpr long readInterval = 3000;        // Interval for reading all sensors (ms)
constexpr long sensorDelayInterval = 500;  // Delay between individual sensor reads (ms)

// Error Handling Constants
constexpr int MAX_READ_ATTEMPTS = 3;    // Max attempts to read a sensor
constexpr int DEFAULT_TEMP = 25.0;      // Default temp if EXT sensor fails (°C)
constexpr int DEFAULT_HUMIDITY = 50.0;  // Default humidity if sensor fails (%)
constexpr int MAX_FAILURES_BEFORE_DISABLE = 10;  // Failures before disabling sensor

// Watchdog Timer Timeout
constexpr int WATCHDOG_TIMEOUT = 8000;  // 8s watchdog timeout (ms)

// Actuator Timing Constants
constexpr unsigned long RETRACT_DURATION = 60000;       // 60s initial retraction (ms)
constexpr unsigned long INITIAL_STOP_DURATION = 10000;  // 10s initial stop (ms)
constexpr unsigned long EXTEND_TIME = 3000;             // 3s extend time (ms)
constexpr unsigned long RETRACT_TIME = 3000;            // 3s retract time (ms)
constexpr unsigned long STOP_TIME = 780000;             // 13 min stop time (ms)
constexpr int REPETITIONS = 11;                         // Number of actuator cycles

// Actuator State Machine
enum State {
  RETRACTING_INITIAL,   // Initial retraction phase
  STOPPING_INITIAL,     // Initial stop phase
  EXTENDING_SEQUENCE,   // Extending sequence phase
  RETRACTING_SEQUENCE,  // Retracting sequence phase
  STOPPING              // Stop phase
};

// Pulse Measurement Constants
constexpr unsigned long MIN_PULSE_DURATION = 1000;    // Min valid pulse duration (µs)
constexpr unsigned long MAX_PULSE_DURATION = 1000000; // Max valid pulse duration (µs)

// Valid Range for Temperature and Humidity
constexpr float MIN_VALID_TEMP = -40.0;    // Min valid temperature (°C)
constexpr float MAX_VALID_TEMP = 85.0;     // Max valid temperature (°C)
constexpr float MIN_VALID_HUMIDITY = 0.0;  // Min valid humidity (%)
constexpr float MAX_VALID_HUMIDITY = 100.0;// Max valid humidity (%)

// I2C Retry Constants
constexpr int MAX_I2C_RETRIES = 3;      // Max retries for I2C communication
constexpr int RETRY_DELAY = 50;         // Delay between I2C retries (ms)
constexpr int BUS_RESET_DELAY = 100;    // Delay after bus reset (ms)
constexpr int BUS_RECOVERY_INTERVAL = 60000;  // Interval to reattempt recovery (ms)

// Sensor Initialization Timeout Constants
constexpr unsigned long SENSOR_INIT_TIMEOUT = 5000;  // 5s timeout per sensor (ms)
constexpr unsigned long TOTAL_INIT_TIMEOUT = 30000;  // 30s total init timeout (ms)

// ====================
// Global Variables
// ====================

// Fan Control Variables
unsigned long previousSensorMillis = 0;  // Last time sensors were read
unsigned long sensorDelayMillis = 0;     // Delay tracker between sensor reads
int sensorIndex = 0;                     // Current sensor being read
bool readingCycleComplete = false;       // Flag for completed sensor cycle

// Dimmable Light Objects
DimmableLightLinearized topLight(topDimmerOutputPin);  // Top dimmer control
DimmableLightLinearized botLight(botDimmerOutputPin);  // Bottom dimmer control

// AHT20 Sensor Object
Adafruit_AHTX0 aht20;  // Single AHT20 sensor instance

// Bot Sensor Data Structure
struct BotSensorData {
  float temperatureD = DEFAULT_TEMP;   // BOT_D temperature (°C)
  float temperatureG = DEFAULT_TEMP;   // BOT_G temperature (°C)
  float humidityD = DEFAULT_HUMIDITY;  // BOT_D humidity (%)
  float humidityG = DEFAULT_HUMIDITY;  // BOT_G humidity (%)
  bool updatedD = false;               // BOT_D update flag
  bool updatedG = false;               // BOT_G update flag
};

BotSensorData botSensorData;  // Bot sensor data instance

// Sensor Health Tracking Structure
struct SensorHealth {
  int successfulReads = 0;  // Count of successful reads
  int failedReads = 0;      // Count of failed reads
};

SensorHealth sensorHealth[NUM_SENSORS];  // Health data for each sensor
bool disabledSensors[NUM_SENSORS] = {false};  // Disabled sensor flags
unsigned long lastSensorCheckMillis = 0;      // Last sensor health check time
constexpr long SENSOR_CHECK_INTERVAL = 60000; // Check disabled sensors every 60s

// Sensor Initialization Tracking
bool sensorInitialized[NUM_SENSORS] = {false};  // Initialization flags

// Cycle Counter
int cycleCounter = 0;  // Tracks completed sensor reading cycles

// Actuator Variables
State currentState = RETRACTING_INITIAL;   // Current actuator state
State previousState = RETRACTING_INITIAL;  // Previous actuator state
unsigned long actuatorPreviousMillis = 0;  // Last actuator state update
int sequenceCount = 0;                     // Actuator sequence counter

// Temperature Reading Arrays
float topTemperatures[N_READINGS] = {0};   // TOP temp readings
float botDTemperatures[N_READINGS] = {0};  // BOT_D temp readings
float botGTemperatures[N_READINGS] = {0};  // BOT_G temp readings

// Humidity Reading Arrays
float topHumidities[N_READINGS] = {0};     // TOP humidity readings
float botDHumidities[N_READINGS] = {0};    // BOT_D humidity readings
float botGHumidities[N_READINGS] = {0};    // BOT_G humidity readings

int readingIndex = 0;                      // Current reading index

// Pulse Measurement Structure
struct PulseData {
  unsigned long startTime = 0;  // Pulse start time (µs)
  unsigned long duration = 0;   // Pulse duration (µs)
  bool pulseDetected = false;   // Pulse detection flag
};

PulseData pulseData[7];  // Pulse data for each fan

// I2C Retry Variables
unsigned long lastI2CRetryMillis = 0;  // Last I2C retry time
unsigned long lastBusResetMillis = 0;  // Last bus reset time
bool busResetInProgress = false;       // Flag for bus reset state

// Next Sequence Tracking
State nextSequenceState = RETRACTING_INITIAL;  // Predicted next significant state
int nextSequenceCount = 0;                     // Next sequence repetition number

// External Temperature Tracking
float extTemperature = DEFAULT_TEMP;  // Store EXT sensor temperature

// ====================
// Non-Blocking Pulse Measurement
// ====================
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
void loop() {
  wdt_reset();  // Reset watchdog at loop start

  unsigned long currentMillis = millis();

  // Actuator State Machine
  logStateChange();
  unsigned long elapsedTime = currentMillis - actuatorPreviousMillis;

  switch (currentState) {
    case RETRACTING_INITIAL:
      if (elapsedTime >= RETRACT_DURATION) {
        actuatorPreviousMillis = currentMillis;
        currentState = STOPPING_INITIAL;
        controlMotor(false, 0);
      } else {
        controlMotor(true, -1);  // Retract
        wdt_reset();  // Prevent reset during long retraction
      }
      break;

    case STOPPING_INITIAL:
      if (elapsedTime >= INITIAL_STOP_DURATION) {
        actuatorPreviousMillis = currentMillis;
        currentState = EXTENDING_SEQUENCE;
      } else {
        controlMotor(false, 0);  // Stop
      }
      break;

    case EXTENDING_SEQUENCE:
      wdt_reset();  // Prevent reset during long sequence
      if (sequenceCount < REPETITIONS) {
        if (elapsedTime < EXTEND_TIME) {
          controlMotor(true, 1);  // Extend
        } else if (elapsedTime < EXTEND_TIME + STOP_TIME) {
          controlMotor(false, 0);  // Stop
        } else {
          actuatorPreviousMillis = currentMillis;
          sequenceCount++;
        }
      } else {
        sequenceCount = 0;
        currentState = RETRACTING_SEQUENCE;
      }
      break;

    case RETRACTING_SEQUENCE:
      wdt_reset();  // Prevent reset during long sequence
      if (sequenceCount < REPETITIONS) {
        if (elapsedTime < RETRACT_TIME) {
          controlMotor(true, -1);  // Retract
        } else if (elapsedTime < RETRACT_TIME + STOP_TIME) {
          controlMotor(false, 0);  // Stop
        } else {
          actuatorPreviousMillis = currentMillis;
          sequenceCount++;
          if (sequenceCount >= REPETITIONS) {
            // Reset of the Arduino after the last RETRACTING_SEQUENCE
            wdt_enable(WDTO_15MS);  // Enable watchdog with 15ms timeout
            while (true) {
              // Infinite loop to trigger watchdog reset
            }
          }
        }
      } else {
        sequenceCount = 0;
        currentState = RETRACTING_INITIAL;
      }
      break;
  }

  wdt_reset();  // Reset after actuator control

  // Sensor Reading
  static bool readingInProgress = false;  // Track reading state
  if (currentMillis - previousSensorMillis >= readInterval && !readingInProgress) {
    previousSensorMillis = currentMillis;
    sensorIndex = 0;
    readingCycleComplete = false;
    readingInProgress = true;  // Start reading cycle
  }

  if (readingInProgress && sensorIndex < NUM_SENSORS && currentMillis - sensorDelayMillis >= sensorDelayInterval) {
    sensorDelayMillis = currentMillis;
    sensors_event_t humidity, temp;

    if (disabledSensors[sensorIndex]) {
      float fallbackTemp = getFallbackTemperature(sensorIndex);
      float fallbackHumidity = getFallbackHumidity(sensorIndex);
      adjustFanAndDimmer(fallbackTemp, fallbackHumidity, static_cast<SensorName>(sensorIndex));
      sensorIndex++;
    } else {
      if (readSensorData(sensorIndex + 2, sensorIndex, humidity, temp)) {  // Success
        if (sensorIndex == EXT) {
          extTemperature = temp.temperature;  // Store EXT temperature
          if (shouldPrint()) {
            Serial.print(getSensorName(static_cast<SensorName>(sensorIndex)));
            Serial.print(" - Temperature: ");
            Serial.print(temp.temperature);
            Serial.print(" °C, Humidity: ");
            Serial.print(humidity.relative_humidity);
            Serial.println(" %");
          }
        } else if (sensorIndex == TOP) {
          if (shouldPrint()) {
            Serial.print(getSensorName(static_cast<SensorName>(sensorIndex)));
            Serial.print(" - Temperature: ");
            Serial.print(temp.temperature);
            Serial.print(" °C, Humidity: ");
            Serial.print(humidity.relative_humidity);
            Serial.println(" %");
          }
          topTemperatures[readingIndex] = temp.temperature;
          topHumidities[readingIndex] = humidity.relative_humidity;
        } else if (sensorIndex == BOT_D) {
          botSensorData.temperatureD = temp.temperature;
          botSensorData.humidityD = humidity.relative_humidity;
          botSensorData.updatedD = true;
          botDTemperatures[readingIndex] = temp.temperature;
          botDHumidities[readingIndex] = humidity.relative_humidity;
        } else if (sensorIndex == BOT_G) {
          botSensorData.temperatureG = temp.temperature;
          botSensorData.humidityG = humidity.relative_humidity;
          botSensorData.updatedG = true;
          botGTemperatures[readingIndex] = temp.temperature;
          botGHumidities[readingIndex] = humidity.relative_humidity;

          if (botSensorData.updatedD && botSensorData.updatedG) {
            float avgTemp = (botSensorData.temperatureD + botSensorData.temperatureG) / 2.0;
            float avgHumidity = (botSensorData.humidityD + botSensorData.humidityG) / 2.0;
            if (shouldPrint()) {
              Serial.print("BOT-Av - Temperature: ");
              Serial.print(avgTemp);
              Serial.print(" °C, Humidity: ");
              Serial.print(avgHumidity);
              Serial.println(" %");
            }
          }
        }
        adjustFanAndDimmer(temp.temperature, humidity.relative_humidity, static_cast<SensorName>(sensorIndex));
        sensorIndex++;
      } else if (currentMillis - sensorDelayMillis >= RETRY_DELAY * MAX_I2C_RETRIES + BUS_RESET_DELAY + 100) {  // Timeout check
        float fallbackTemp = getFallbackTemperature(sensorIndex);
        float fallbackHumidity = getFallbackHumidity(sensorIndex);
        adjustFanAndDimmer(fallbackTemp, fallbackHumidity, static_cast<SensorName>(sensorIndex));
        sensorIndex++;
      }
    }

    if (sensorIndex >= NUM_SENSORS) {
      readingCycleComplete = true;
      readingInProgress = false;  // End reading cycle
    }
  }

  if (readingCycleComplete) {
    if (shouldPrint()) {
      Serial.println();
      printFanRPMs();
      printAverages();
      printHumidityAverages();  // Print humidity averages after temperature averages
    }

    printNextSequence();  // Print the next actuator sequence

    cycleCounter++;
    if (cycleCounter >= PRINT_CYCLE_INTERVAL * 10) {  // Reset after 10 intervals
      cycleCounter = 0;  // Reset cycle counter appropriately
    }

    printSensorHealth();  // Print health status every cycle
    if (shouldPrint()) {
      Serial.println();
    }
    readingCycleComplete = false;
    readingIndex = (readingIndex + 1) % N_READINGS;
  }

  wdt_reset();  // Reset after sensor reading

  // Pulse Measurement
  measurePulseNonBlocking(TACH_F1BG, 0);
  measurePulseNonBlocking(TACH_F2BD, 1);
  measurePulseNonBlocking(TACH_F3BC, 2);
  measurePulseNonBlocking(TACH_F4HG, 3);
  measurePulseNonBlocking(TACH_F5EXT, 4);
  measurePulseNonBlocking(TACH_F6BC, 5);
  measurePulseNonBlocking(TACH_F7HD, 6);

  // Check and re-enable sensors periodically
  checkDisabledSensors();
}

// ====================
// Additional Functions
// ====================

void printFanRPMs() {
  if (shouldPrint()) {
    unsigned long rpmF1BG = calculateRPMNonBlocking(0);
    unsigned long rpmF2BD = calculateRPMNonBlocking(1);
    unsigned long rpmF3BC = calculateRPMNonBlocking(2);
    unsigned long rpmF4HG = calculateRPMNonBlocking(3);
    unsigned long rpmF5EXT = calculateRPMNonBlocking(4);
    unsigned long rpmF6BC = calculateRPMNonBlocking(5);
    unsigned long rpmF7HD = calculateRPMNonBlocking(6);

    Serial.print("EXT: F5EXT: ");
    Serial.print(rpmF5EXT);
    Serial.println(" RPM");

    Serial.print("TOP: F4HG: ");
    Serial.print(rpmF4HG);
    Serial.print(" RPM,");
    Serial.print(" F7HD: ");
    Serial.print(rpmF7HD);
    Serial.println(" RPM");

    Serial.print("BOT: F1BG: ");
    Serial.print(rpmF1BG);
    Serial.print(" RPM, F2BD: ");
    Serial.print(rpmF2BD);
    Serial.print(" RPM, F3BC: ");
    Serial.print(rpmF3BC);
    Serial.print(" RPM,");
    Serial.print(" F6BC: ");
    Serial.print(rpmF6BC);
    Serial.println(" RPM"); 
    Serial.println();
    
  }
}
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

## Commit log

2025-07-07 Add arduino project and documentation
    [fritzing-wiring-plan.fzz]
2025-07-07 deployment flow fix
